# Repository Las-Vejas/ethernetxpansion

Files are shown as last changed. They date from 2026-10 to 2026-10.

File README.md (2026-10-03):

# ethernetxpansion

This is an ethernet adapter for the [Hackxpansion console](https://github.com/hackclub/hackxpansion). It uses the WIZnet W5500 chip and the Hanrun HR911105A ethernet plug.

<h2 align="center">Pictures</h2>

<p align="center">
  Kaze screenshot 1
  Kaze screenshot 2
</p>

<p align="center">
  Kaze photo 1
  Kaze photo 2
  Kaze photo 3
</p>

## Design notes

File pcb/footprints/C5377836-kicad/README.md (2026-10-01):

# HCTL HC621601A-M911-A (LCSC C5377836) - KiCad symbol, footprint, 3D model

## Read this first: what is built, what is sourced, what is NOT verified
Built by me: the symbol, the footprint and an updated simplified 3D model.
Sourced from the HCTL drawing (datasheet.pdf): all pad positions and drill sizes, body outline, pin names, LED polarity.
NOT verified:
- I could not run KiCad here. No KiCad 10, no ERC, no DRC, no 3D viewer check. The files were only parsed with a third-party S-expression library (kiutils) and paren-checked. I wrote them in the KiCad 9 file format, which KiCad 10 should open and upgrade on save. Open them once and tell me if anything is rejected.
- The symbol was never rendered. Check how it looks in the symbol editor.
- No physical part, no PCB fit test, no solder test.
- Pad sizes (1.6 mm signal, 1.7 mm LED, 2.6 mm shield) are my choice. The drawing only gives drill sizes. Check against your fab rules.
- The two 3.20 mm locating-post holes are non-plated (NPTH). The drawing does not say plated or not.
- The 3D model is still the simplified one (see below), not manufacturer CAD.

## Correction to the earlier 3D model
Re-reading the drawing for the footprint, I found the earlier STEP had pin Y positions off by 0.11-0.22 mm: signal rows were 9.00/6.46 mm from the post line instead of 8.89/6.35 mm, and the LED pins were 3.89 mm instead of 4.11 mm. I fixed model.py and regenerated STEP/STL; the 3dshapes/ files here replace the earlier ones. All 14 pin centers in the STEP now match the footprint pads (checked numerically, 0.0000 mm difference). Port, contact and tab details are still approximations.

## Files
- HCTL.kicad_sym: symbol HC621601A-M911-A
- HCTL.pretty/RJ45_HCTL_HC621601A-M911-A_Vertical_TH.kicad_mod: footprint
- 3dshapes/HC621601A-M911-A.step (+ .stl): simplified 3D model, origin = midpoint of the locating posts at PCB surface
- source/model.py (CadQuery), source/gen_kicad.py (regenerates symbol + footprint), source/datasheet.pdf
- fp_preview.png: plot of the footprint pads read back from the file (not a KiCad screenshot)

## Footprint (datasheet page 1 "recommended PCB layout", component side)
Origin = midpoint of the two locating posts. Pin 1 = square pad at (5.715, 8.89) in KiCad coordinates, bottom-right.
- Pins 1-10: drill 0.90, pad 1.6. Rows 2.54 apart, 1.27 stagger, 2.54 pitch. Odd pins at y=+8.89, even at y=+6.35.
- Pins 11-14 (LEDs): drill 1.02, pad 1.7, at x = +-3.785 and +-6.325, y = -4.11.
- Locating posts: 2x NPTH 3.20 at x = +-5.715, y = 0.
- Shield: 2x pad "SH", drill 1.63, pad 2.6, at x = +-7.95, y = +3.89.
- Fab outline 16.10 x 16.90 mm. The connector opening faces up, away from the PCB; the LED/latch side is toward the top of the pad view (-Y).

## Symbol pins (datasheet page 3, all typed passive so ERC will not complain about power pins)
1 VCC_CT (datasheet "VCC", PHY-side center-tap bus) | 2 TD1+ | 3 TD1- | 4 TD2+ | 5 TD2- | 6 TD3+ | 7 TD3- | 8 TD4+ | 9 TD4- | 10 GND_BS (datasheet "GND", cable-side 75 ohm termination via 1000 pF/2 kV)
11 LED_G_A / 12 LED_G_K (green) | 13 LED_Y_A / 14 LED_Y_K (yellow). Anode/cathode taken from the diode symbols on page 3.
SH = shield. The symbol's Footprint field is HCTL:RJ45_HCTL_HC621601A-M911-A_Vertical_TH, LCSC field is C5377836.
Check pin 1 (VCC_CT) against your PHY's magnetics requirements before routing; I only transcribed the drawing.

## Install
1. Copy HCTL.pretty/, HCTL.kicad_sym and 3dshapes/ into your project folder.
2. Preferences > Manage Symbol Libraries: add project library, nickname HCTL, path ${KIPRJMOD}/HCTL.kicad_sym.
3. Manage Footprint Libraries: add nickname HCTL, path ${KIPRJMOD}/HCTL.pretty.
4. The footprint's 3D path is ${KIPRJMOD}/3dshapes/HC621601A-M911-A.step. If you put the folder elsewhere, change it in the footprint's 3D settings. No rotation or offset should be needed; if the model looks mirrored or offset, tell me.

## Source
https://www.lcsc.com/product-detail/C5377836.html
https://datasheet.lcsc.com/datasheet/pdf/a6450734ef0cdf4aa798ffe8304b55e8.pdf?productCode=C5377836

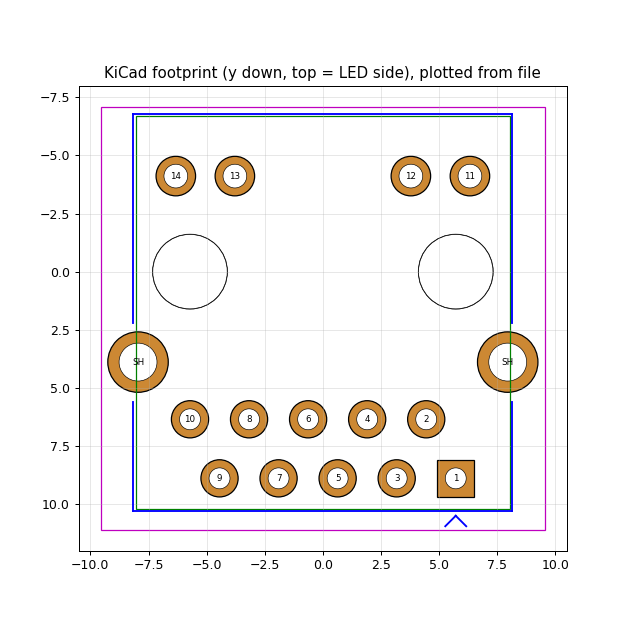
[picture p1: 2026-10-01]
pcb/footprints/C5377836-kicad/fp_preview.png

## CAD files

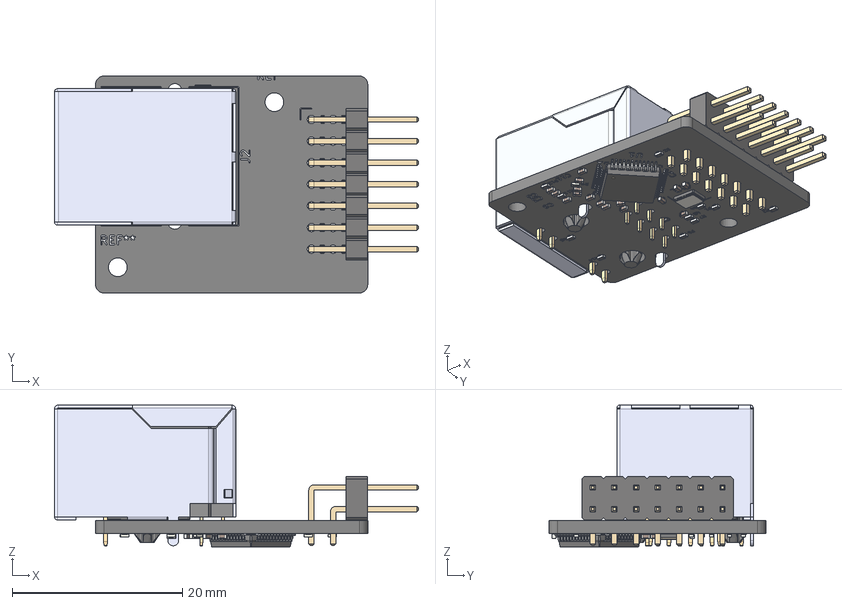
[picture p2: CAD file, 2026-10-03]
3d/PCB.step
42.8 x 25.5 x 16.7 mm
PinHeader_2x07_P254mm_Horizontal
HR911105A_yellow_led
HR911105A_pin_001
HR911105A_pin_002
HR911105A_pin_003
HR911105A_pin_004
HR911105A_pin_005
HR911105A_pin_006
HR911105A_pin_007
HR911105A_pin_008
HR911105A_pin_009
HR911105A_pin_010
HR911105A_contact_004
HR911105A_contact_003
HR911105A_contact_002
HR911105A_contact_001
HR911105A_red_led
HR911105A_pin_011
HR911105A_pin_012
HR911105A_contact_005
HR911105A_contact_006
HR911105A_contact_007
HR911105A_contact_008
HR911105A_outer_shield
HR911105A_inner_023
R_0402_1005Metric x 12
C_0402_1005Metric x 16
Crystal_SMD_3225-4Pin_3.2x2.5mm
LQFP-48_7x7mm_P0.5mm
ethernetxpansion_silkscreen x 2
ethernetxpansion_PCB

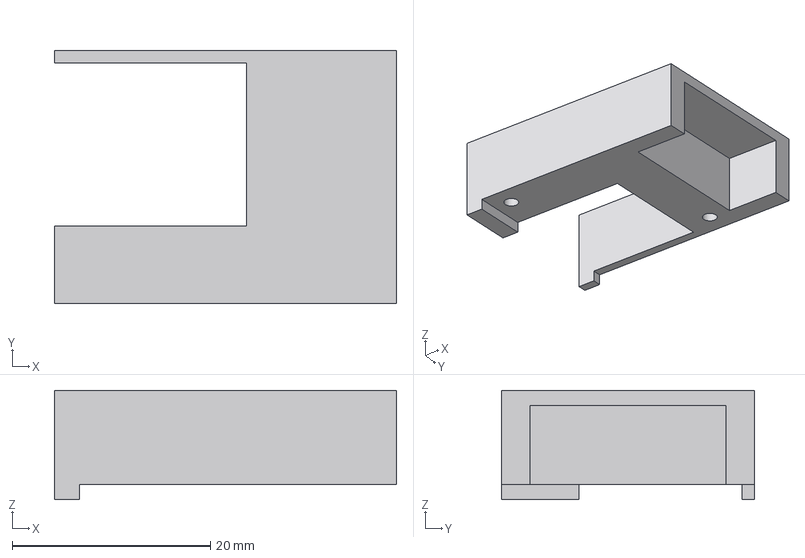
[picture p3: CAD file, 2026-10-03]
3d/ethxpansionCASE.step
34.5 x 25.5 x 11.0 mm

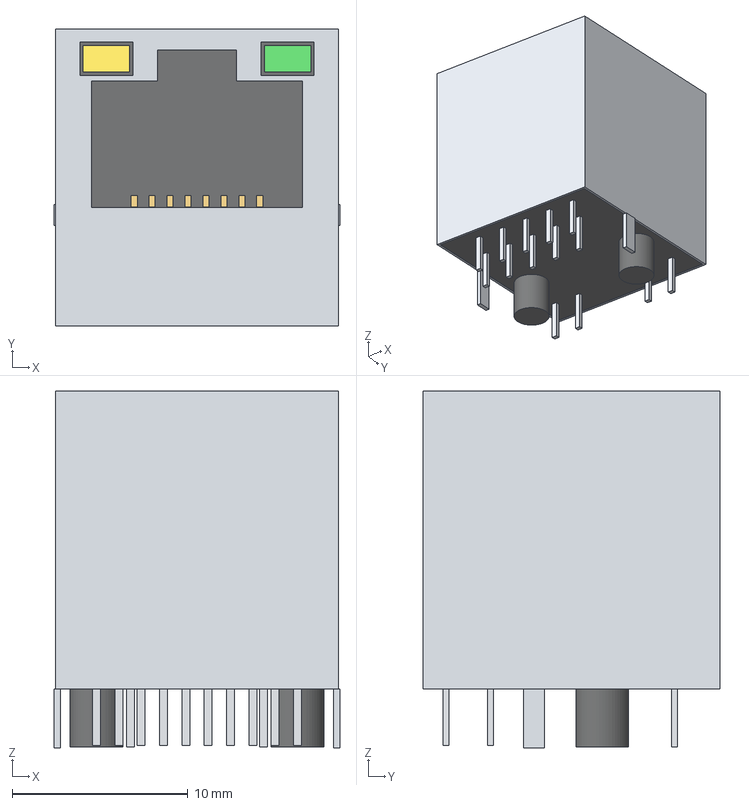
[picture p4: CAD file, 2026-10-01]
pcb/footprints/C5377836-kicad/3dshapes/HC621601A-M911-A.step
16.2 x 16.9 x 20.3 mm
nickel_shield
LCP_housing
yellow_LED
green_LED
contact_1
contact_2
contact_3
contact_4
contact_5
contact_6
contact_7
contact_8
pin_2
pin_1
pin_4
pin_3
pin_6
pin_5
pin_8
pin_7
pin_10
pin_9
LED_pin_14
LED_pin_13
LED_pin_12
LED_pin_11
locating_post_-1
shield_tab_-1
locating_post_1
shield_tab_1

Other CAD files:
pcb/footprints/C5377836-kicad/3dshapes/HC621601A-M911-A.stl

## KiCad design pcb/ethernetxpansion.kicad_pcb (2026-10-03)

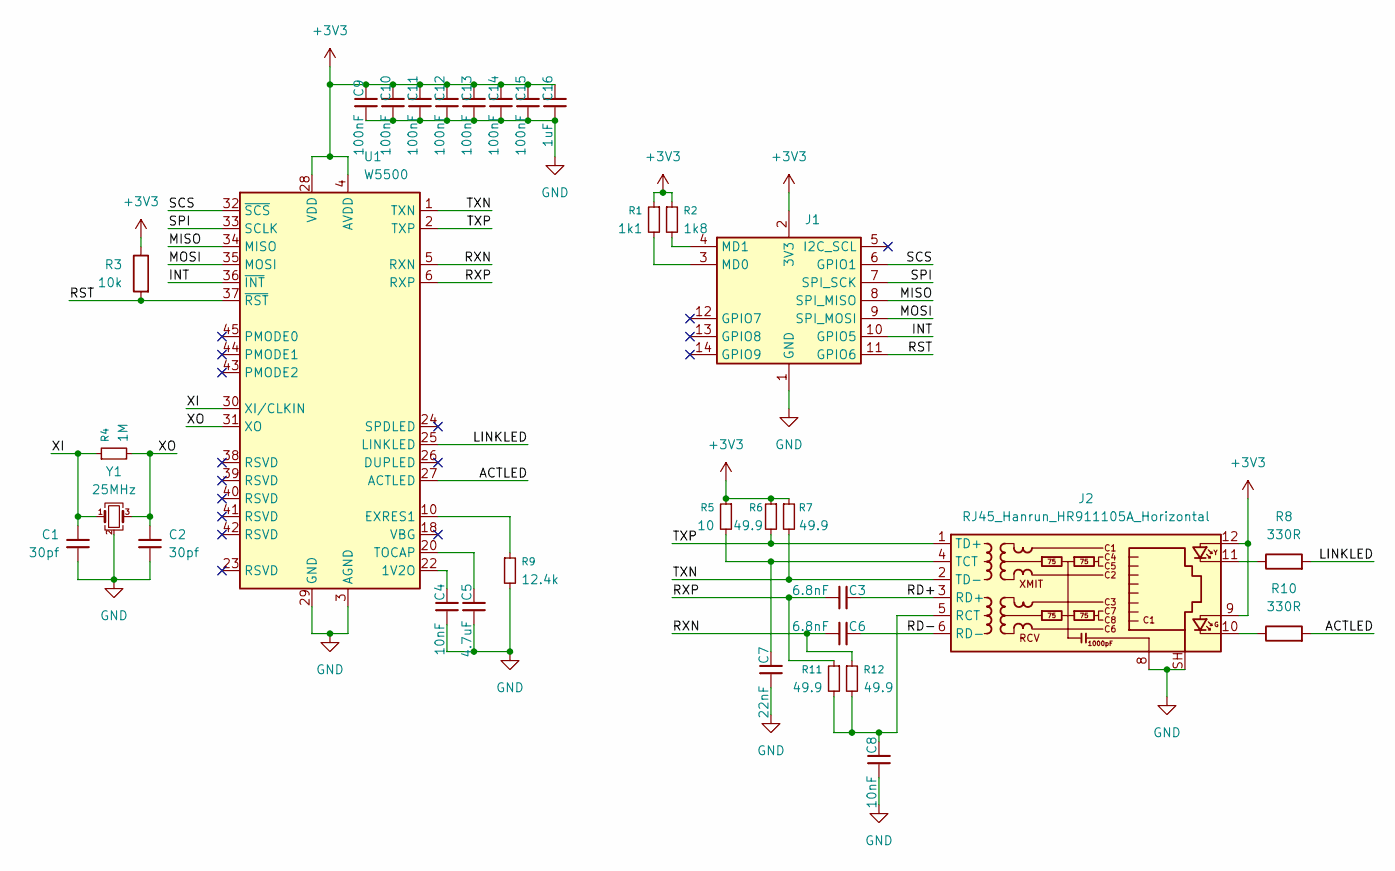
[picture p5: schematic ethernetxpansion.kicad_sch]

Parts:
C1, C2: 30pf; C_0402_1005Metric
C3, C6: 6.8nF; C_0402_1005Metric
C4, C8: 10nF; C_0402_1005Metric
C5: 4.7uF; C_0402_1005Metric
C7: 22nF; C_0402_1005Metric
C9, C10, C11, C12, C13, C14, C15: 100nF; C_0402_1005Metric
C16: 1uF; C_0402_1005Metric
J1: Male_Module
J2: RJ45_Hanrun_HR911105A_Horizontal
R1: 1k1; R_0402_1005Metric
R2: 1k8; R_0402_1005Metric
R3: 10k; R_0402_1005Metric
R4: 1M; R_0402_1005Metric
R5: 10; R_0402_1005Metric
R6, R7, R11, R12: 49.9; R_0402_1005Metric
R8, R10: 330R; R_0402_1005Metric
R9: 12.4k; R_0402_1005Metric
U1: W5500; LQFP-48_7x7mm_P0.5mm
Y1: 25MHz; Crystal_SMD_3225-4Pin_3.2x2.5mm

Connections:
+3V3: C9.2, C10.2, C11.2, C12.2, C13.2, C14.2, C15.2, C16.2, J1.2 (3V3), J2.9, J2.12, R1.1, R2.1, R3.1, R5.1, R6.1, R7.1, U1.4 (AVDD), U1.8 (AVDD), U1.11 (AVDD), U1.15 (AVDD), U1.17 (AVDD), U1.21 (AVDD), U1.28 (VDD)
/ACTLED: R10.2, U1.27 (ACTLED)
/INT: J1.10 (GPIO5), U1.36 (~INT)
/LINKLED: R8.2, U1.25 (LINKLED)
/MISO: J1.8 (SPI_MISO), U1.34 (MISO)
/MOSI: J1.9 (SPI_MOSI), U1.35 (MOSI)
/RD+: C3.2, J2.3 (RD+)
/RD-: C6.2, J2.6 (RD-)
/RST: J1.11 (GPIO6), R3.2, U1.37 (~RST)
/RXN: C6.1, R12.1, U1.5 (RXN)
/RXP: C3.1, R11.1, U1.6 (RXP)
/SCS: J1.6 (GPIO1), U1.32 (~SCS)
/SPI: J1.7 (SPI_SCK), U1.33 (SCLK)
/TXN: J2.2 (TD-), R7.2, U1.1 (TXN)
/TXP: J2.1 (TD+), R6.2, U1.2 (TXP)
/XI: C1.1, R4.1, U1.30 (XI/CLKIN), Y1.1
/XO: C2.1, R4.2, U1.31 (XO), Y1.3
GND: C1.2, C2.2, C4.1, C5.1, C7.1, C8.1, C9.1, C10.1, C11.1, C12.1, C13.1, C14.1, C15.1, C16.1, J1.1 (GND), J2.8, J2.SH, R9.2, U1.3 (AGND), U1.9 (AGND), U1.14 (AGND), U1.16 (AGND), U1.19 (AGND), U1.29 (GND), U1.48 (AGND), Y1.2 (G), Y1.4 (G)
unnamed: J1.3 (MD0), R1.2
unnamed: J1.4 (MD1), R2.2
unnamed: J2.10, R10.1
unnamed: J2.11, R8.1
unnamed: C8.2, J2.5 (RCT), R11.2, R12.2
unnamed: C7.2, J2.4 (TCT), R5.2
unnamed: C4.2, U1.22 (1V2O)
unnamed: R9.1, U1.10 (EXRES1)
unnamed: C5.2, U1.20 (TOCAP)

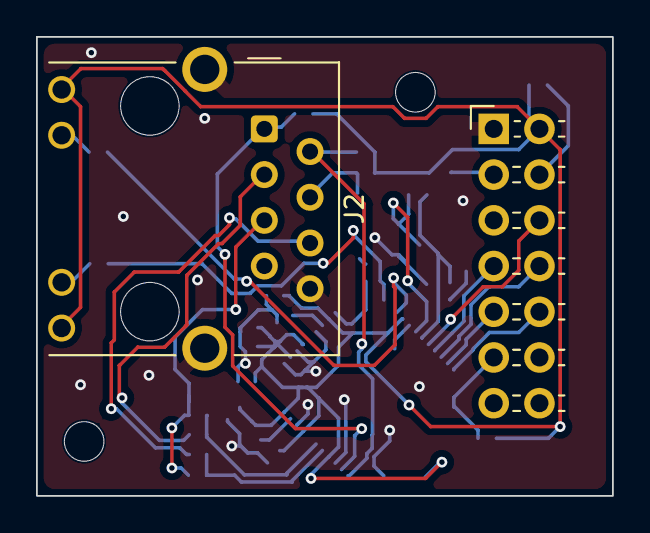
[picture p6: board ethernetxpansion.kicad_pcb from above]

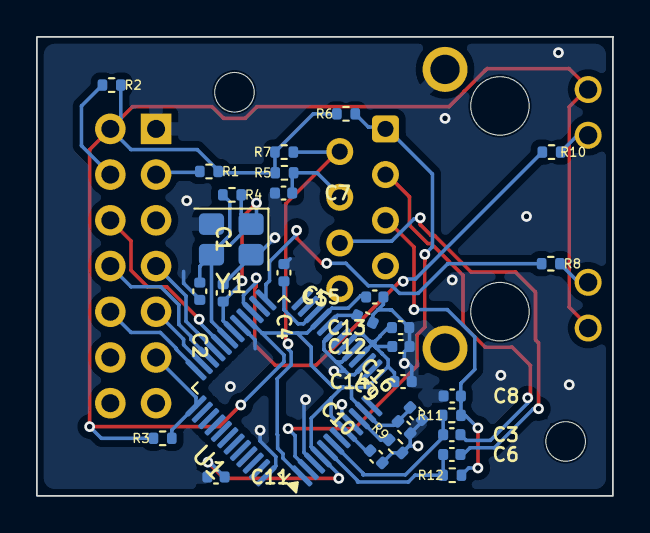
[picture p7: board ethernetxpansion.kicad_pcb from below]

Board: 4 copper layers, 32.0 x 25.5 mm, 32 parts (30 on the bottom side), 27 nets.

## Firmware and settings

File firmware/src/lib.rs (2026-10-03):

#![no_std]
pub mod net;
use embassy_rp::{
    bind_interrupts,
    gpio::{Input, Level, Output, Pull},
    peripherals::{DMA_CH2, DMA_CH3},
    spi,
};

use xpanse_api::{
    bus::{
        allocator::BusAllocator,
        spi::SpiBusHandle,
    },
    driver::{Driver, DriverError, DriverMeta},
    gpio_bank::{BankPins, GpioBank},
    metadata::{ModuleDetectResistor, ModuleID, ModuleSlot},
    registry::Registry,
};

pub const SPI_FREQUENCY: u32 = 30_000_000;

// Both DMA_CH2 and DMA_CH3 use DMA_IRQ_0 on the RP235x.
bind_interrupts!(pub struct Irqs {
    DMA_IRQ_0 =>
        embassy_rp::dma::InterruptHandler<DMA_CH2>,
        embassy_rp::dma::InterruptHandler<DMA_CH3>;
});

pub struct Ethernet {
    pub spi: SpiBusHandle,
    pub cs: Output<'static>,
    pub int: Input<'static>,
    pub rst: Output<'static>,
}

pub struct EthernetDriver;

impl DriverMeta for EthernetDriver {
    const ID: ModuleID = ModuleID {
        md0: ModuleDetectResistor::R1K1,
        md1: ModuleDetectResistor::R1K8,
    };
}

impl<G: BankPins> Driver<G> for EthernetDriver {
    async fn create(
        gpio_bank: GpioBank<G>,
        slot: ModuleSlot,
        registry: &mut Registry,
        bus_allocator: &mut BusAllocator,
    ) -> Result<(), DriverError> {

        let mut config = spi::Config::default();
        config.frequency = SPI_FREQUENCY;

        let spi = bus_allocator
            .create_spi_hardware::<G::SPI, DMA_CH2, DMA_CH3, _>(
                gpio_bank.gpio2, // SCK
                gpio_bank.gpio4, // MOSI
                gpio_bank.gpio3, // MISO
                Irqs,
                config,
            )
            .map_err(|_| DriverError::InitFailed)?;

        let cs = Output::new(
            gpio_bank.gpio1,
            Level::High,
        );

        let int = Input::new(
            gpio_bank.gpio5,
            Pull::Up,
        );

        let rst = Output::new(
            gpio_bank.gpio6,
            Level::High,
        );

        registry.register(
            slot,
            Self::ID,
            Ethernet {
                spi,
                cs,
                int,
                rst,
            },
        );

        Ok(())
    }
}

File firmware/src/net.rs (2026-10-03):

use embassy_rp::gpio::{Input, Output};
use embassy_time::Delay;

use embedded_hal_bus::spi::ExclusiveDevice;

use embassy_net_wiznet::{
    chip::W5500,
    Device,
    InitError,
    Runner,
    State,
};

use xpanse_api::bus::spi::{SpiBusHandle, SpiError};

use crate::Ethernet;

pub type EthSpiDevice =
    ExclusiveDevice<SpiBusHandle, Output<'static>, Delay>;

pub type EthRunner<'a> =
    Runner<'a, W5500, EthSpiDevice, Input<'static>, Output<'static>>;

pub type EthDevice<'a> = Device<'a>;


pub const N_RX: usize = 8;
pub const N_TX: usize = 8;

pub type EthState = State<N_RX, N_TX>;


pub const DEFAULT_MAC: [u8; 6] = [0x02, 0x00, 0x00, 0x45, 0x54, 0x48];


/// Resets the W5500 and builds an `embassy-net` device for it.
///
/// The returned `EthRunner` must be driven forever (`runner.run().await`)
/// in its own task, and the `EthDevice` is handed to
/// `embassy_net::new` to get a TCP/IP stack.
pub async fn create_network<'a>(
    eth: Ethernet,
    mac_addr: [u8; 6],
    state: &'a mut EthState,
) -> Result<
    (EthDevice<'a>, EthRunner<'a>),
    InitError<
        embedded_hal_bus::spi::DeviceError<SpiError, core::convert::Infallible>,
    >,
> {
    let spi_device = ExclusiveDevice::new(
        eth.spi,
        eth.cs,
        Delay,
    )
    .expect("Failed to create SPI device for W5500");

    embassy_net_wiznet::new::<N_RX, N_TX, W5500, _, _, _>(
        mac_addr,
        state,
        spi_device,
        eth.int,
        eth.rst,
    )
    .await
}
